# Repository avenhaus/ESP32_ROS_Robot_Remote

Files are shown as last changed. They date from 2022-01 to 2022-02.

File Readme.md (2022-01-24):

<!-- PROJECT LOGO -->
<br />
<div align="center">
  <a href="https://github.com/avenhaus/ESP32_ROS_Robot_Remote">
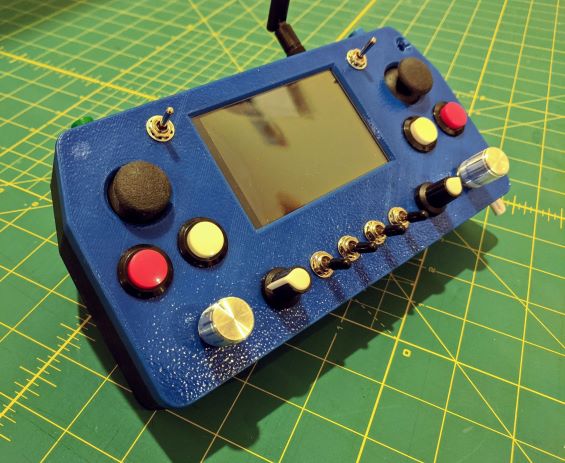
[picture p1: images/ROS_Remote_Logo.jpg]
    
  </a>

<h3 align="center">ESP32 ROS Robot Remote</h3>

  <p align="center">
    This is a universal Robot-OS (ROS) remote control based on an ESP32 microcontroller. 
  </p>
</div>

<!-- ABOUT THE PROJECT -->
## About The Project

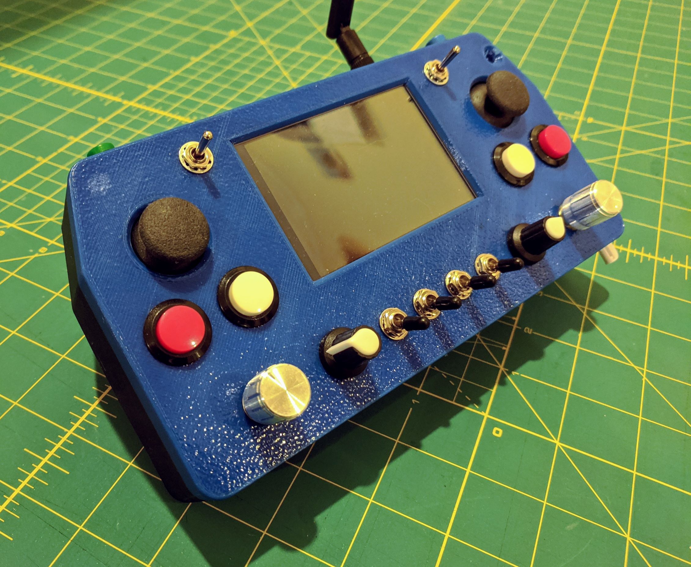
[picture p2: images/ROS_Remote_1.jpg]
ESP32 ROS Robot Remote


### Project State
This is still a work in progress. Basic functionality like publishing all the controls to a ROS1 topic is working.

### Features

* ESP32 connecting to ROS via WIFI
* 3.5" Touch LCD 480 x 320
* 2 x analog X/Y gamepad joysticks with push switch
* 2 x analog potentiometer
* 2 x rotary encoder with push switch (KY-040)
* 4 x 2-position toggle switches
* 2 x 3-position toggle switches
* 8 x push buttons
* 18650 Li-Ion battery
* External WIFI antenna for better range
* SD-card reader
* Integrated stylus holder
* Optional feet
* Quick startup time
* OTA update
* Low cost

## Configuration

### ROS Topics

```
> rostopic info remote_joy
Type: sensor_msgs/Joy

> rostopic echo remote_joy

header: 
  seq: 211
  stamp: 
    secs: 50
    nsecs: 497000000
  frame_id: "remote"
axes: [-0.011300298385322094, -0.011915299110114574, 0.0, 0.1590232104063034, -0.011768353171646595, -0.011577111668884754, 0.0, 0.754769504070282]
buttons: [0, 0, 0, 0, 0, 0, 0, 0, 0, 0, 0, 0, 0, 0, 0, 0, 0, 0, 0, 0]

```

## TODO

* Code cleanup, license and documentation
* Code for Display
* Web Configuration
* Build instructions
* ROS-2 support
* PCB

## Images

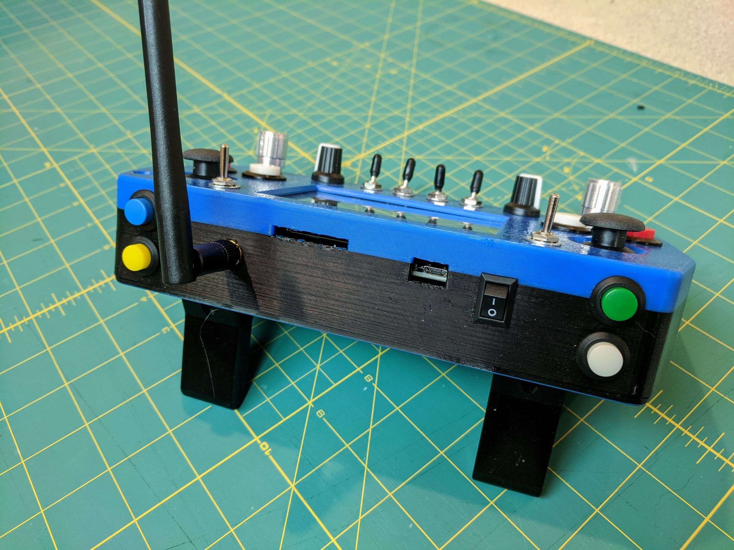
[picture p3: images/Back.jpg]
Back

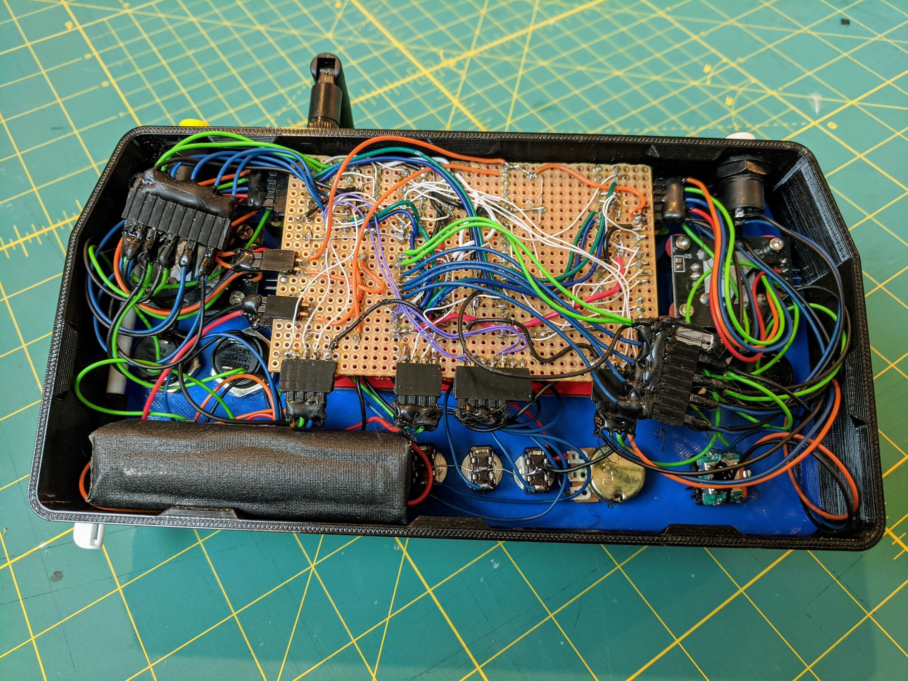
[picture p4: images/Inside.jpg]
Inside

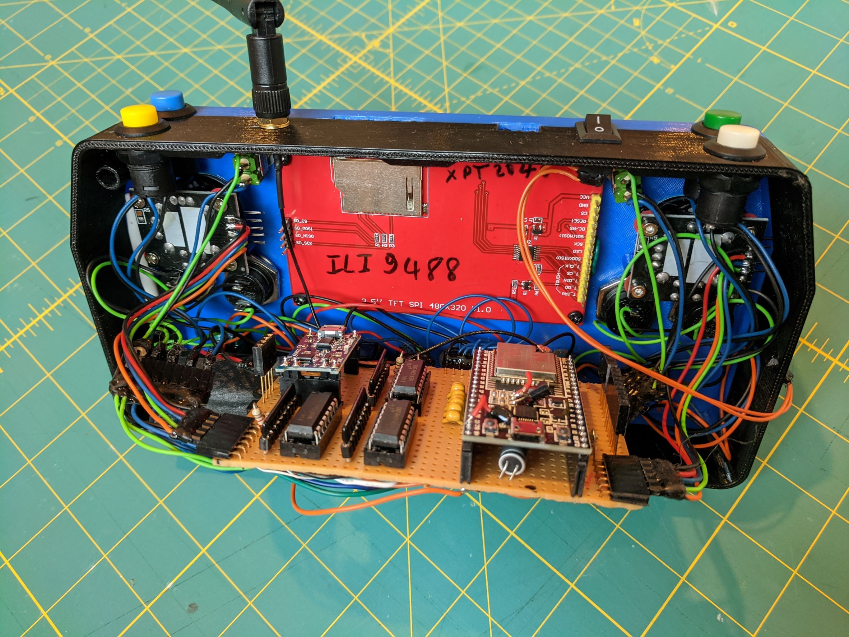
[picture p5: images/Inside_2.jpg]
Inside 2

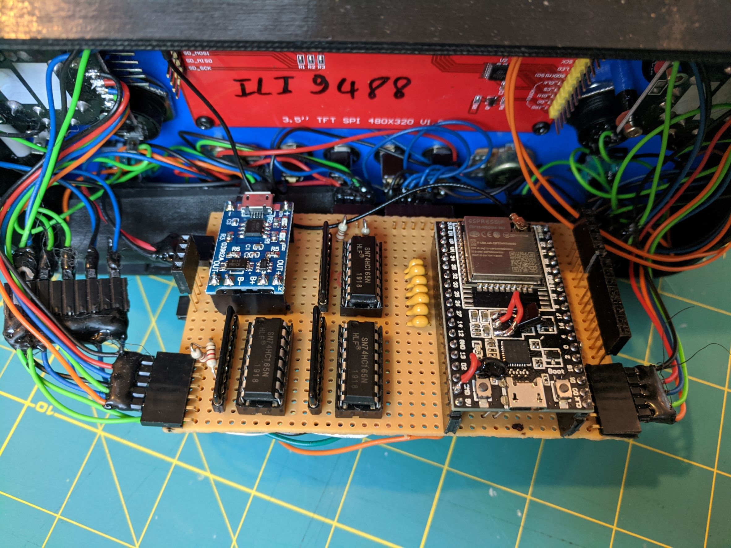
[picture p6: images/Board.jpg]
Board

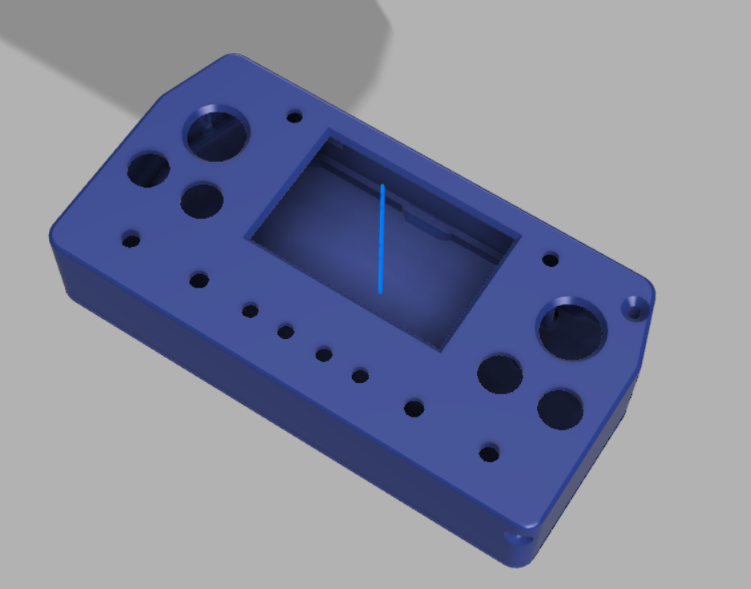
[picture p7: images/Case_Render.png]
Case Render

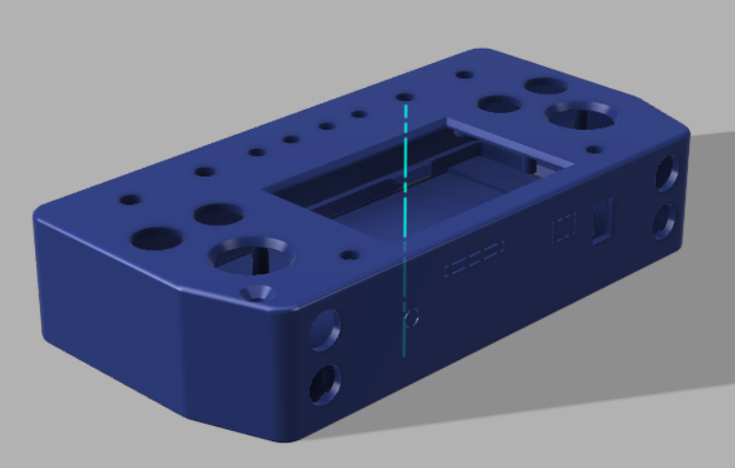
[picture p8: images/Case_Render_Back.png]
Case Render Back

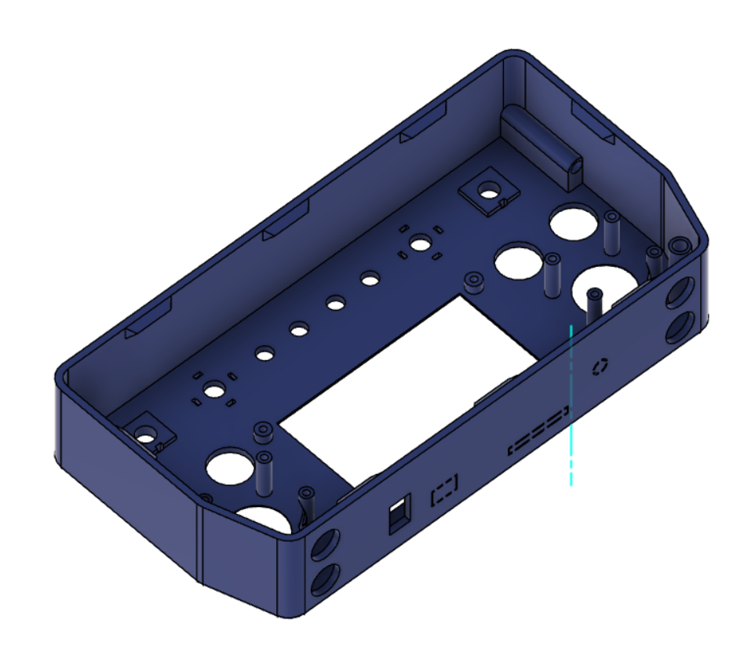
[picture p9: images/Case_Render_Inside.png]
Case Render Inside


## Links
* [ROS - Robot Operating System](https://www.ros.org/)

## Credits
Inspired by James Bruton [Touchscreen Smart Robot Remote](https://www.youtube.com/watch?v=ATQblGOjMWQ)

Web UI is inspired by and somewhat based on [ESP3D-WEBUI](https://github.com/luc-github/ESP3D-WEBUI) and [FluidNC](https://github.com/bdring/FluidNC)

<p align="right">(<a href="#top">back to top</a>)</p>

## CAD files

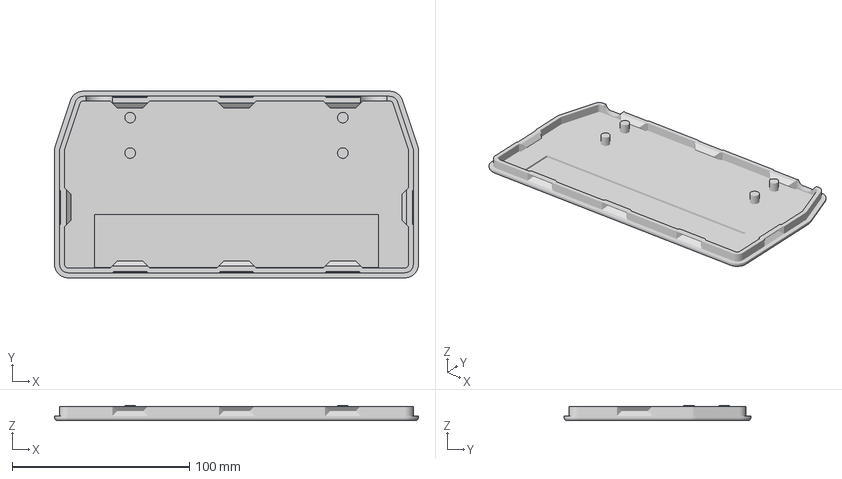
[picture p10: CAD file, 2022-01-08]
hardware/Enclosure/Cover.3mf
205.4 x 105.4 x 8.70 mm

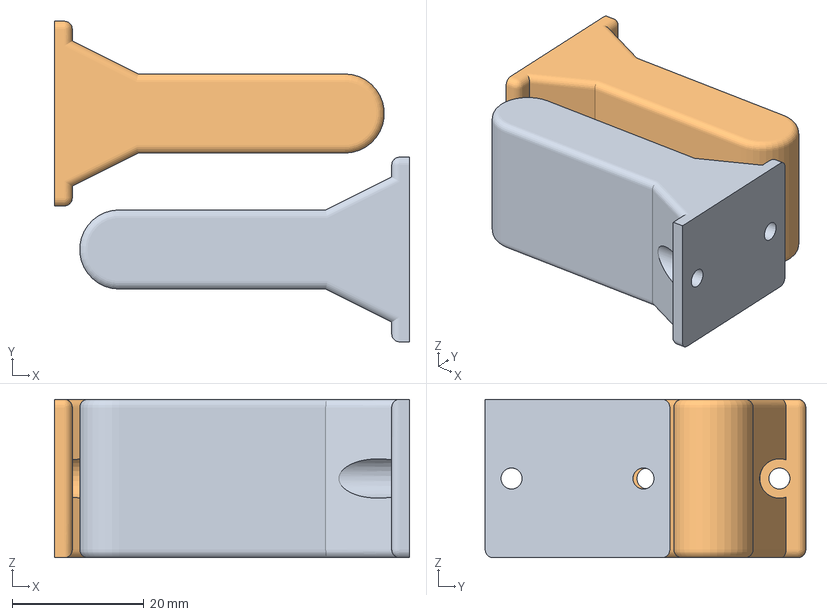
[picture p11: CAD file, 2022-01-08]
hardware/Enclosure/Remote_Feet.3mf
53.8 x 48.6 x 24.0 mm
Foot x 2

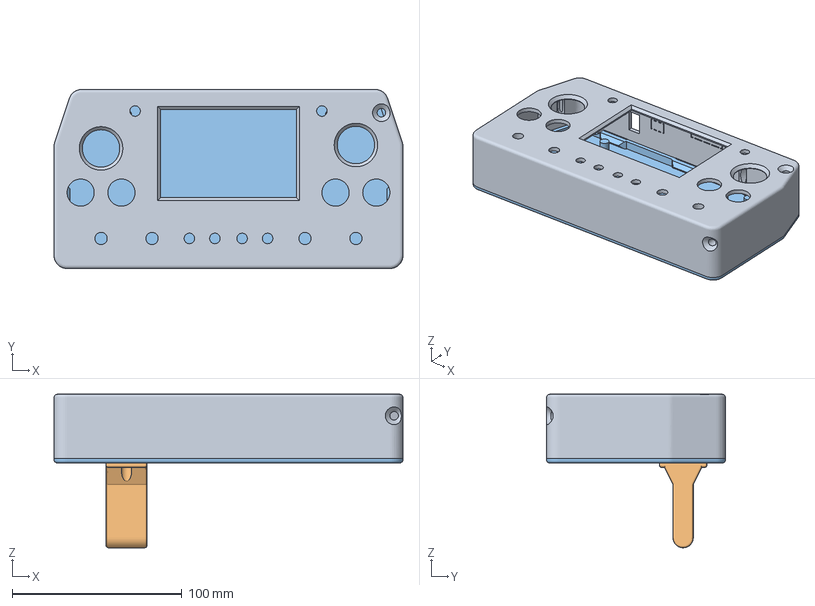
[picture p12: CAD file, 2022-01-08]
hardware/Enclosure/Remote.3mf
205.4 x 105.4 x 90.4 mm
Case
Foot
Lid

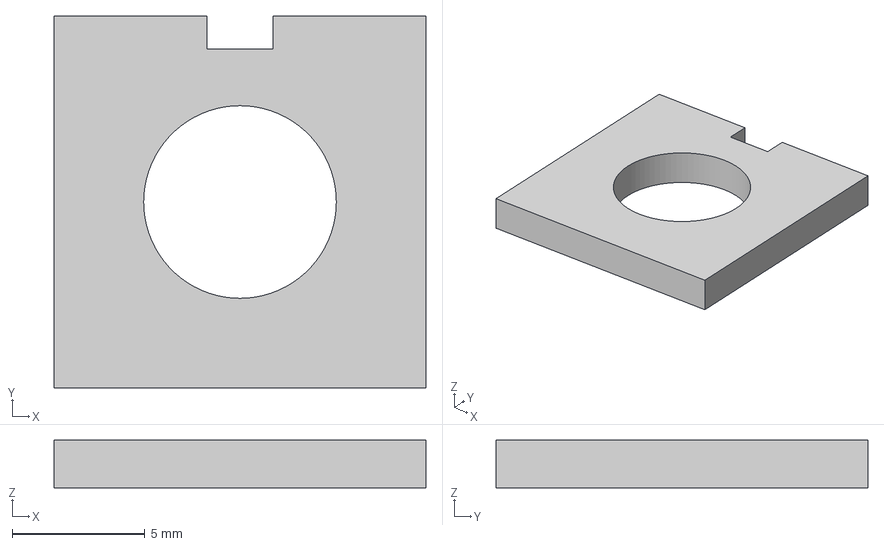
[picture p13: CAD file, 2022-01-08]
hardware/Enclosure/EncSpacer.3mf
14.0 x 14.0 x 1.80 mm

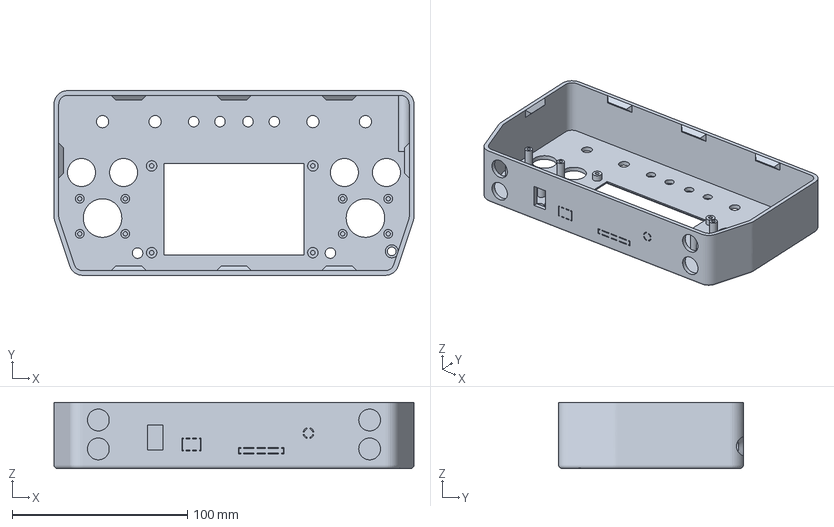
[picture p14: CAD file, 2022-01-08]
hardware/Enclosure/Remote_Body.3mf
205.4 x 105.4 x 37.7 mm

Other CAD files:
hardware/Enclosure/Remote_Lid.3mf
hardware/Enclosure/Remote.f3d

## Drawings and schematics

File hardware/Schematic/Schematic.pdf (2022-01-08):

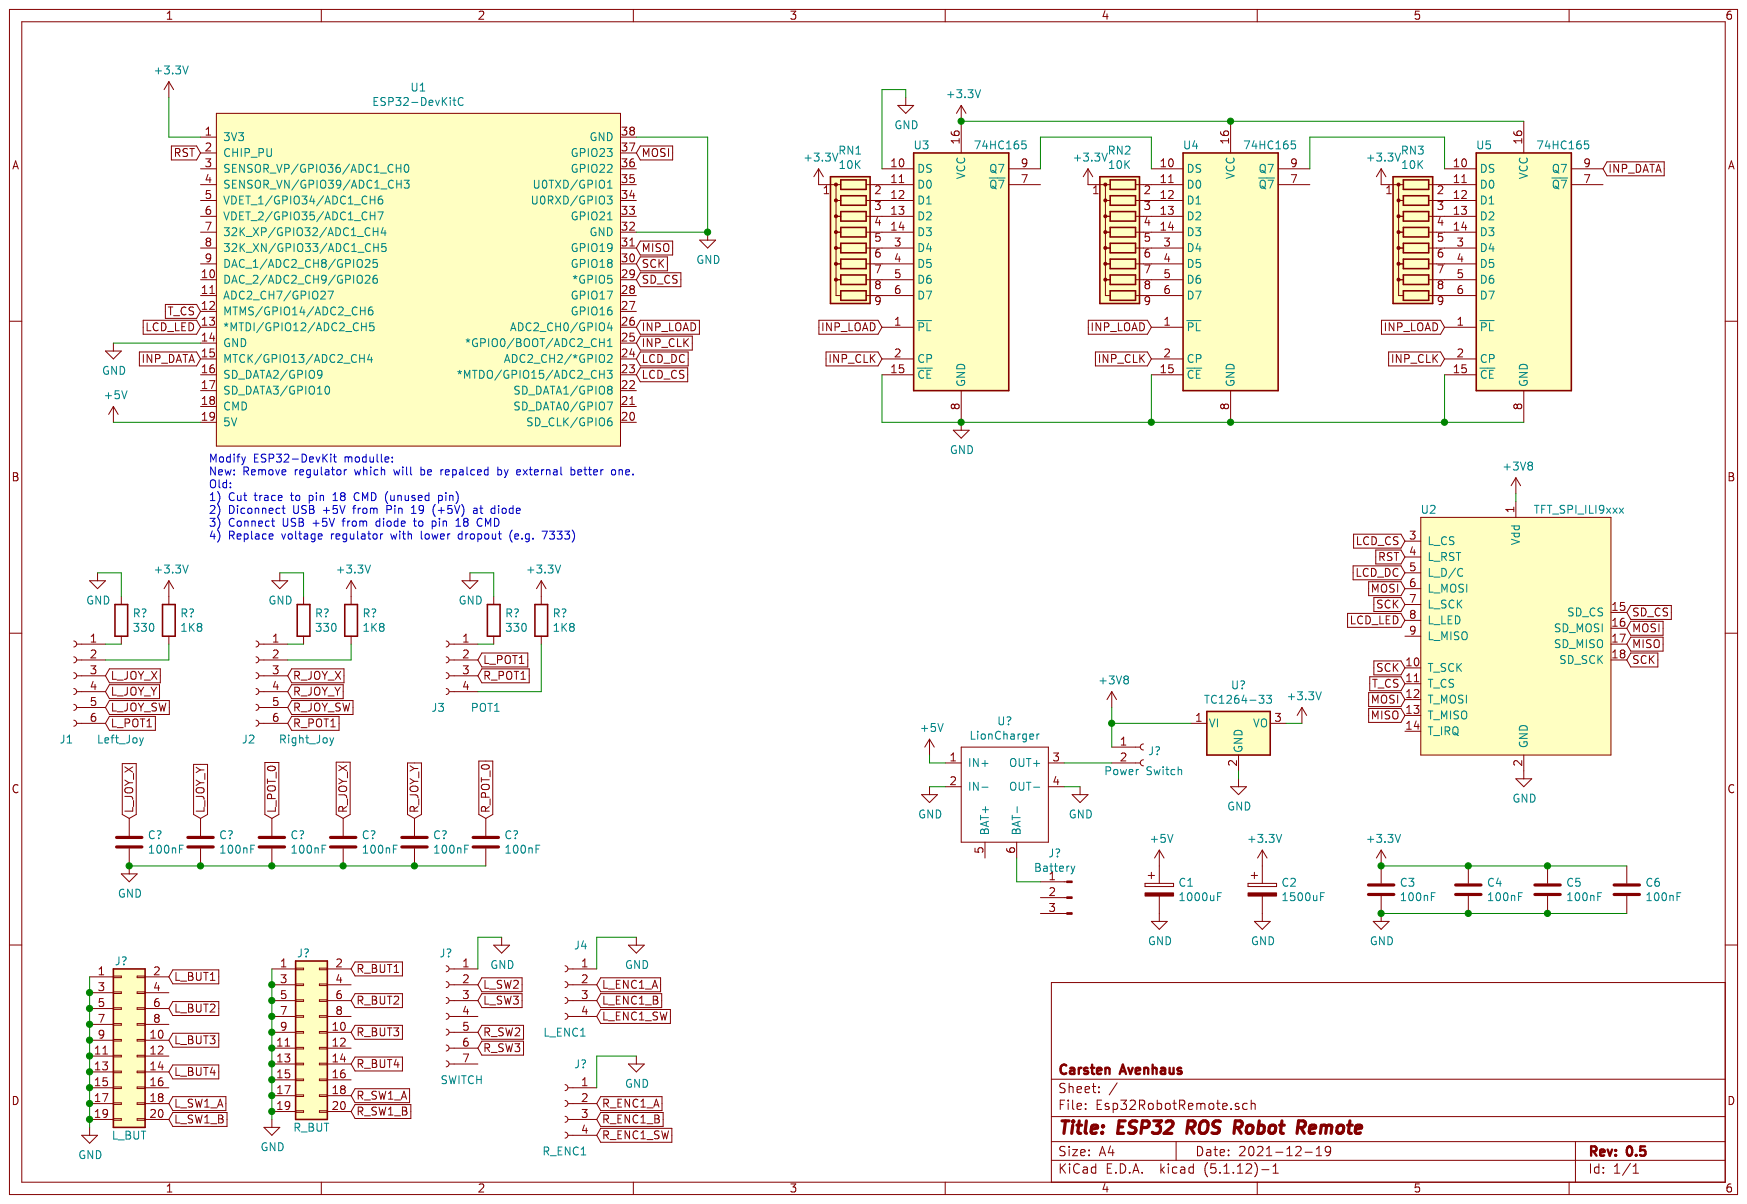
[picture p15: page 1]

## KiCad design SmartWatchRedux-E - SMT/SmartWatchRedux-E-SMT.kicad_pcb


Board: 2 copper layers, 24.7 x 69.9 mm, 6 parts (0 on the bottom side), 33 nets.

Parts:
BAT1: CR2032; BatteryHolder_Keystone_1060_1x2032
C1: 0.1uF; C_1206_3216Metric
CN1: 27C256Socket; DIP-28_W15.24mm
U1: ROM; DIP-28_W15.24mm_Socket
U2: DS1315; DIP-16_W7.62mm
Y1: 32.768 KHz; Crystal_SMD_3215-2Pin_3.2x1.5mm

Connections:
/XTAL1: U2.1, Y1.1
/XTAL2: U2.2, Y1.2
GND: BAT1.2, C1.2, CN1.14, U1.14, U2.5, U2.8, U2.14
unnamed: BAT1.1, U2.4
unnamed: CN1.1, U1.1, U2.13
unnamed: CN1.2, U1.2
unnamed: CN1.3, U1.3
unnamed: CN1.4, U1.4
unnamed: CN1.5, U1.5
unnamed: CN1.6, U1.6
unnamed: CN1.7, U1.7
unnamed: CN1.8, U1.8, U2.3
unnamed: CN1.9, U1.9
unnamed: CN1.10, U1.10, U2.6
unnamed: CN1.11, U1.11, U2.7
unnamed: CN1.12, U1.12
unnamed: CN1.13, U1.13
unnamed: CN1.15, U1.15
unnamed: CN1.16, U1.16
unnamed: CN1.17, U1.17
unnamed: CN1.18, U1.18
unnamed: CN1.19, U1.19
unnamed: CN1.20, U2.11
unnamed: CN1.21, U1.21
unnamed: CN1.22, U1.22, U2.12
unnamed: CN1.23, U1.23
unnamed: CN1.24, U1.24
unnamed: CN1.25, U1.25
unnamed: CN1.26, U1.26
unnamed: CN1.27, U1.27
unnamed: U1.20, U2.10
unnamed: U2.9, U2.15
VCC: C1.1, CN1.28, U1.28, U2.16

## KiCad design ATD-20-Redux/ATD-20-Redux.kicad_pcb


Board: 2 copper layers, 24.3 x 64.1 mm, 5 parts (0 on the bottom side), 9 nets.

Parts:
BAT1: CR2032; BatteryHolder_Keystone_1060_1x2032
C1: 0.1uF; C_Disc_D4.3mm_W1.9mm_P5.00mm
J1: RTC Pins; DIP-28_W15.24mm_Socket
U1: DS1315; DIP-16_W7.62mm
Y1: 32.768 KHz; Crystal_C38-LF_D3.0mm_L8.0mm_Horizontal

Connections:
/D0: J1.11, U1.6, U1.7
/XTAL1: U1.1, Y1.1
/XTAL2: U1.2, Y1.2
/~CS_RTC: J1.20, U1.11
/~IOR: J1.22, U1.12
/~IOW: J1.27, U1.3
GND: BAT1.2, C1.2, J1.14, U1.5, U1.8, U1.9, U1.14
unnamed: BAT1.1, U1.4
VCC: C1.1, J1.28, U1.13, U1.16

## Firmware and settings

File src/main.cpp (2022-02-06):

/*======================================================================*\
 * ESP32 ROS Remote Controller
\*======================================================================*/

#include <Arduino.h>

#include "Config.h"
#include "VUEF.h"
#include "SPIFFS.h"
#include "Display.h"
#include "ROS1.h"
#include "Analog.h"
#include "Battery.h"
#include "Encoder.h"


void extendedInputSetup();
uint32_t getExtendedInputs();
extern uint32_t extended_inputs;
extern uint32_t old_extended_inputs;

Encoder encoderLeft;
Encoder encoderRight;

Joystick leftJoyX(L_JOY_X_PIN);
Joystick leftJoyY(L_JOY_Y_PIN);
Joystick leftJoyR(L_JOY_R_PIN);
Potentiometer leftPot1(L_POT1_PIN);

Joystick rightJoyX(R_JOY_X_PIN);
Joystick rightJoyY(R_JOY_Y_PIN);
Joystick rightJoyR(R_JOY_R_PIN);
Potentiometer rightPot1(R_POT1_PIN);

uint32_t analogReadTs = 0;

float joyAxes[JOY_AXIS_SIZE] = {0};
int32_t joyButtons[JOY_BUTTON_SIZE] = {0};

uint32_t inputSameCount = 0;


void setup() {
  adcInit();
  adc2RegSave(); // Save ADC2 registers before WiFi

  pinMode(LED_PIN, OUTPUT);
  digitalWrite(LED_PIN, HIGH);  

  vuefInit();

  // This must be executed before Display initialization.
  // Otherwise SPI gets messed up for some reason.
  extendedInputSetup();

  #if ENABLE_DISPLAY
  displaySetup();
  displayBootScreen();  
  DEBUG_print(F("Screen Done\n"));
  #endif
  
  rosInit();

  #if ENABLE_DISPLAY
  mainScreen();
  #endif
  //digitalWrite(LED_PIN, HIGH);  
}

void loop() {
  vuefRun();
 
  getExtendedInputs();  
  if (extended_inputs != old_extended_inputs) { inputSameCount = 0; }
  else { inputSameCount++; }
  if (inputSameCount == 5) { // Simple debounce
  
    joyButtons[L_JOY_BUTTON_ENC] = encoderLeft.update((extended_inputs >> LEFT_ENCODER1_A_BIT) & 3);
    joyButtons[L_JOY_BUTTON_ENCB] = !EX_INPUT(LEFT_ENCODER1_BUTTON_BIT);
    joyButtons[R_JOY_BUTTON_ENC] = encoderRight.update((extended_inputs >> RIGHT_ENCODER1_A_BIT) & 3);
    joyButtons[R_JOY_BUTTON_ENCB] = !EX_INPUT(RIGHT_ENCODER1_BUTTON_BIT);

    DEBUG_printf(FST("Inputs: %08X  L:%d  R:%d \n"), ~extended_inputs, encoderLeft.counter, encoderRight.counter);

    joyButtons[L_JOY_BUTTON_JOY] = !EX_INPUT(LEFT_BUTTON_JOY_BIT);
    joyButtons[L_JOY_BUTTON_I1] = !EX_INPUT(LEFT_BUTTON_I1_BIT);
    joyButtons[L_JOY_BUTTON_I2] = !EX_INPUT(LEFT_BUTTON_I2_BIT);
    joyButtons[L_JOY_BUTTON_T1] = !EX_INPUT(LEFT_BUTTON_T1_BIT);
    joyButtons[L_JOY_BUTTON_T2] = !EX_INPUT(LEFT_BUTTON_T2_BIT);
    joyButtons[L_JOY_BUTTON_SW1] = !EX_INPUT(LEFT_BUTTON_SW1_BIT);
    joyButtons[L_JOY_BUTTON_SW2] = !EX_INPUT(LEFT_BUTTON_SW2_BIT);
    joyButtons[L_JOY_BUTTON_DSW1] = !EX_INPUT(LEFT_BUTTON_DSW1A_BIT) ? 1 : !EX_INPUT(LEFT_BUTTON_DSW1B_BIT) ? -1 : 0;

    joyButtons[R_JOY_BUTTON_JOY] = !EX_INPUT(RIGHT_BUTTON_JOY_BIT);
    joyButtons[R_JOY_BUTTON_I1] = !EX_INPUT(RIGHT_BUTTON_I1_BIT);
    joyButtons[R_JOY_BUTTON_I2] = !EX_INPUT(RIGHT_BUTTON_I2_BIT);
    joyButtons[R_JOY_BUTTON_T1] = !EX_INPUT(RIGHT_BUTTON_T1_BIT);
    joyButtons[R_JOY_BUTTON_T2] = !EX_INPUT(RIGHT_BUTTON_T2_BIT);
    joyButtons[R_JOY_BUTTON_SW1] = !EX_INPUT(RIGHT_BUTTON_SW1_BIT);
    joyButtons[R_JOY_BUTTON_SW2] = !EX_INPUT(RIGHT_BUTTON_SW2_BIT);
    joyButtons[R_JOY_BUTTON_DSW1] = !EX_INPUT(RIGHT_BUTTON_DSW1A_BIT) ? 1 : !EX_INPUT(RIGHT_BUTTON_DSW1B_BIT) ? -1 : 0;

    //DEBUG_printf(FST("Inputs: %04X %d\n"), extended_inputs, joyButtons[L_JOY_BUTTON_ENC]);
  }

  uint32_t now = millis();
  if (now - analogReadTs >= 2) {
    analogReadTs = now;
    joyAxes[L_JOY_AXIS_X] = leftJoyX.read();
    joyAxes[L_JOY_AXIS_Y] = leftJoyY.read();
    joyAxes[L_JOY_AXIS_R] = leftJoyR.read();
    joyAxes[L_JOY_AXIS_P] = leftPot1.read();

    joyAxes[R_JOY_AXIS_X] = rightJoyX.read();
    joyAxes[R_JOY_AXIS_Y] = rightJoyY.read();
    joyAxes[R_JOY_AXIS_R] = rightJoyR.read();
    joyAxes[R_JOY_AXIS_P] = rightPot1.read();
    //DEBUG_printf(FST("Analog: LX %d  %.3f %.3f  LP %d  %.3f %.3f  LY %d   RX %d  RY %d  RP %d\n"), leftJoyX.raw, leftJoyX.value, leftJoyX.fvalue, leftPot1.raw, leftPot1.value, leftPot1.fvalue, leftJoyY.raw, rightJoyX.raw, rightJoyY.raw, rightPot1.raw);
    //DEBUG_printf(FST("Analog: LY %d  %.3f %.3f \n"), leftJoyY.raw, leftJoyY.value, leftJoyY.fvalue);
    //DEBUG_printf(FST("Analog: LX %4d  %.3f | LY %4d  %.3f | LP %4d  %.3f || RX %4d  %.3f | RY %4d  %.3f | RP %4d  %.3f\n"), leftJoyX.raw, leftJoyX.fvalue, leftJoyY.raw, leftJoyY.fvalue, leftPot1.raw, leftPot1.fvalue, rightJoyX.raw, rightJoyX.fvalue, rightJoyY.raw, rightJoyY.fvalue, rightPot1.raw, rightPot1.fvalue);

  }

  #if ENABLE_DISPLAY
  guiRun();
  #endif

 
  #if BATTERY_PIN >= 0 
  batteryRun(now);
  if (batteryChargeLevel <= 2) {
    //  DEBUG_println(FST("Battery is low!"));
    // shutdown();
  }
  #endif

  //vTaskDelay(100);

}

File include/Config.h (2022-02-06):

#ifndef CONFIG_H
#define CONFIG_H

#include <Arduino.h>

/********************************************\
|*  Pin Definitions
\********************************************/

/*
https://drive.google.com/file/d/1gbKM7DA7PI7s1-ne_VomcjOrb0bE2TPZ/view
---+------+----+-----+-----+-----------+---------------------------
No.| GPIO | IO | RTC | ADC | Default   | Function
---+------+----+-----+-----+-----------+---------------------------
25 |   0* | IO | R11 | 2_1 | Boot      | INPUT_CLK
35 |   1  | IO |     |     | UART0_TXD | USB Programming/Debug
24 |   2* | IO | R12 | 2_2 |           | LCD_DC
34 |   3  | IO |     |     | UART0_RXD | USB Programming/Debug
26 |   4* | IO | R10 | 2_0 |           | INPUT_LOAD
29 |   5* | IO |     |     | SPI0_SS   | SD_CS (LED)  
14 |  12* | IO | R15 | 2_5 |           | LCD_LED
16 |  13  | IO | R14 | 2_4 |           | INPUT_IN (or INPUT_CS)
13 |  14  | IO | R16 | 2_6 |           | TOUCH_CS
23 |  15* | IO | R13 | 2_3 |           | LCD_CS
27 |  16+ | IO |     |     | UART2_RXD | 
28 |  17+ | IO |     |     | UART2_TXD | 
30 |  18  | IO |     |     | SPI0_SCK  | SCK LCD,Touch,SD
31 |  19  | IO |     |     | SPI0_MISO | MISO Touch, SD
33 |  21  | IO |     |     | I2C0_SDA  | Buzzer 
36 |  22  | IO |     |     | I2C0_SCL  | 
37 |  23  | IO |     |     | SPI0_MOSI | MOSI LCD, SD
10 |  25  | IO | R06 | 2_8 |DAC1/I2S-DT| Battery
11 |  26  | IO | R07 | 2_9 |DAC2/I2S-WS| 
12 |  27  | IO | R17 | 2_7 | I2S-BCK   | 
8  |  32  | IO | R09 | 1_4 |           | Pot_R
9  |  33  | IO | R08 | 1_5 |           | R_JOY_Y
6  |  34  | I  | R04 | 1_6 |           | R_JOY_X
7  |  35  | I  | R05 | 1_7 |           | Pot_L
4  |  36  | I  | R00 | 1_0 | SENSOR_VP | L_JOY_Y
5  |  39  | I  | R03 | 1_3 | SENSOR_VN | L_JOY_X
3  |  EN  | I  |     |     | RESET     | Reset LCD       
---+------+----+-----+-----+-----------+---------------------------
(IO6 to IO11 are used by the internal FLASH and are not useable)
22 x I/O  + 4 x input only = 26 usable pins 
GPIO_34 - GPIO_39 have no internal pullup / pulldown.
- ADC2 can not be used with WIFI/BT (easily)
+ GPIO 16 and 17 are not available on WROVER (PSRAM)
* Strapping pins: IO0, IO2, IO4, IO5 (HIGH), IO12 (LOW), IO15 (HIGH)
*/

#define LCD_SCK_PIN 18
#define LCD_MOSI_PIN 23
#define LCD_MISO_PIN 19
#define LCD_RST_PIN -1
#define LCD_DC_PIN 2
#define LCD_CS_PIN 15
#define LCD_LED_PIN 12
#define LCD_LED_PWM_CHANNEL 0

#define TOUCH_CS_PIN 14
#define TOUCH_CS_IRQ -1

#define SD_CS_PIN 5
#define LED_PIN 5

#define BUZZER_PIN 21

#define INPUT_SPI_CHANNEL VSPI
#define INPUT_SPI_SPEED 10000000
#define INPUT_SCK_PIN 0
#define INPUT_LOAD_PIN 4 // 74HC165 HIGH during shifting
#define INPUT_MISO_PIN 13

#define ADC_VREF 1100

#define BATTERY_PIN -1
#define R_POT1_PIN 34
#define L_POT1_PIN 33

#define R_JOY_X_PIN 36 
#define R_JOY_Y_PIN 39 
#define R_JOY_R_PIN -1

#define L_JOY_X_PIN 35 
#define L_JOY_Y_PIN 32 
#define L_JOY_R_PIN -1

/* ============================================== *\
 * Extended Inputs (from shift registers 74HC165)
\* ============================================== */

#define LEFT_ENCODER1_A_BIT 22
#define LEFT_ENCODER1_B_BIT 23
#define LEFT_ENCODER1_BUTTON_BIT 21

#define RIGHT_ENCODER1_A_BIT 18
#define RIGHT_ENCODER1_B_BIT 19
#define RIGHT_ENCODER1_BUTTON_BIT 20

#define LEFT_BUTTON_JOY_BIT 17
#define LEFT_BUTTON_I1_BIT 28 
#define LEFT_BUTTON_I2_BIT 29
#define LEFT_BUTTON_T1_BIT 30
#define LEFT_BUTTON_T2_BIT 31
#define LEFT_BUTTON_SW1_BIT 10
#define LEFT_BUTTON_SW2_BIT 11
#define LEFT_BUTTON_DSW1A_BIT 24
#define LEFT_BUTTON_DSW1B_BIT 25

#define RIGHT_BUTTON_JOY_BIT 16
#define RIGHT_BUTTON_I1_BIT 12 
#define RIGHT_BUTTON_I2_BIT 13
#define RIGHT_BUTTON_T1_BIT 14
#define RIGHT_BUTTON_T2_BIT 15
#define RIGHT_BUTTON_SW1_BIT 26
#define RIGHT_BUTTON_SW2_BIT 27
#define RIGHT_BUTTON_DSW1A_BIT 9
#define RIGHT_BUTTON_DSW1B_BIT 8


#define EX_INPUT(BIT) (BIT < 0 ? 0 : (extended_inputs >> BIT) & 1)


/* ============================================== *\
 * Constants
\* ============================================== */

#define ENABLE_DISPLAY 1

#define ROS1_HOST "192.168.0.155"
#define ROS1_PORT 11411


typedef enum JoyAxis {
    L_JOY_AXIS_X,
    L_JOY_AXIS_Y,
    L_JOY_AXIS_R,
    L_JOY_AXIS_P,
    R_JOY_AXIS_X,
    R_JOY_AXIS_Y,
    R_JOY_AXIS_R,
    R_JOY_AXIS_P,
    JOY_AXIS_SIZE
} JoyAxis;
extern float joyAxes[JOY_AXIS_SIZE];

typedef enum JoyButton {
    L_JOY_BUTTON_JOY,
    L_JOY_BUTTON_I1,
    L_JOY_BUTTON_I2,
    L_JOY_BUTTON_T1,
    L_JOY_BUTTON_T2,
    L_JOY_BUTTON_SW1,
    L_JOY_BUTTON_SW2,
    L_JOY_BUTTON_DSW1,
    L_JOY_BUTTON_ENC,
    L_JOY_BUTTON_ENCB,
    R_JOY_BUTTON_JOY,
    R_JOY_BUTTON_I1,
    R_JOY_BUTTON_I2,
    R_JOY_BUTTON_T1,
    R_JOY_BUTTON_T2,
    R_JOY_BUTTON_SW1,
    R_JOY_BUTTON_SW2,
    R_JOY_BUTTON_DSW1,
    R_JOY_BUTTON_ENC,
    R_JOY_BUTTON_ENCB,
    JOY_BUTTON_SIZE
} JoyButton;
extern int32_t joyButtons[JOY_BUTTON_SIZE];


#endif

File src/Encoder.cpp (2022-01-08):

#include <Arduino.h>
#include "Encoder.h"

// Encoder Lookup table
static const int8_t ENCODER_STATES[] PROGMEM = {0,-1,1,0,1,0,0,-1,-1,0,0,1,0,1,-1,0}; 

// KY-040 generates pulses of about 5ms and as low as 2ms.
// KY-040 generates a lot of noise. The lookup table helps to deal with that.
int32_t Encoder::update(uint8_t inputAB) {
  _oldAB <<=2;        // Remember previous state
  _oldAB |= inputAB & 3;  // Update with new state

  _state += ENCODER_STATES[( _oldAB & 0x0F )];

  // Update counter if encoder has rotated a full indent, that is at least 4 steps
  if( _state > 3 ) {        // Four steps forward
    counter++;              // Increase counter
    _state = 0;
  } else if( _state < -3 ) {  // Four steps backwards
    counter--;               // Decrease counter
    _state = 0;
  }
  return counter;
}

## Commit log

2022-01-10 Work on new configuration framework
2022-01-15 New Configuration Registry framework
2022-01-24 - New Command framework - Start of WebUI
2022-01-28 Hide passwords and allow variables to be filtered based on flags.
2022-01-29 Dynamically show WebUI files tab/button based on config.basic response. Some bug fixes.
    [Command.cpp, Files.cpp]
2022-02-06 Start of framework library
2022-03-23 Moved common things into framework library VUEF
